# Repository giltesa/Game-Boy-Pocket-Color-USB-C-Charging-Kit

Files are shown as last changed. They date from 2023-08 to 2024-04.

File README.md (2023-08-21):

# Game Boy Pocket/Color: USB-C Charging Kit (GB2)

The **Game Boy Pocket/Color: USB-C Charging Kit**, or **GB2** as I like to call it, is a circuit that replaces the original power board of the **Game Boy Pocket** and **Game Boy Color**.

This circuit is a **multi-device** and versatile board with **multiple installation options**. This means that **this kit can be used for both Game Boy models**, and you can decide whether you want to **power your console with AA/AAA** batteries **or a rechargeable li-ion battery**. You can also choose between using the **original 2.5mm DC power connector** **or replacing it with a USB-C**. Additionally, you have **the option to install a light board that will indicate the status of the console and battery**, all from the original hole on the console, next to the screen.





### FEATURES

*   Exact **shape for Game Boy Pocket & Game Boy Color**.
*   **Power DC converter** of **5V** output. **(1)**
*   **External power** through **2.5mm DC jack** or **USB-C.** **(2)**
*   **Li-Ion battery charger** with overvoltage and undervoltage protection. **(2)**
*   **Safe charge and play**.
*   **Integrated LED indicators** on the main board, next to the battery connector for charging battery (red) and full battery (green). It can be disabled by the jumper SJ1.
*   **External LED indicators** board for playing (white), charging battery (red) and full battery (green). Optional installation.

**(1)** Provides stable power to your Game Boy, IPS screen, and flash card. However, it doesn't supply the -19v rail, which means the stock screen or GBP IPS screen, which adjusts brightness through the contrast wheel, will not be able to change the brightness level and will remain at its maximum level.

**(2)** The USB-C and li-ion battery require trimming of the shell. Please refer to the PDF installation manual for more information.

https://www.youtube.com/watch?v=UszhrSf1U5U

## Would you like it?

https://shop.giltesa.com/product/game-boy-pocket-color-usb-c-charging-kit/

## More

- [giltesa.com](https://giltesa.com "giltesa.com")
- [twitter.com](https://twitter.com/giltesa "twitter.com")

## License

This project is licensed under a **Creative Commons** license:
**[Attribution-NonCommercial-ShareAlike 4.0 International (CC BY-NC-SA 4.0) ](https://creativecommons.org/licenses/by-nc-sa/4.0/)**

Check the [LICENSE.md](LICENSE.md) for more information.

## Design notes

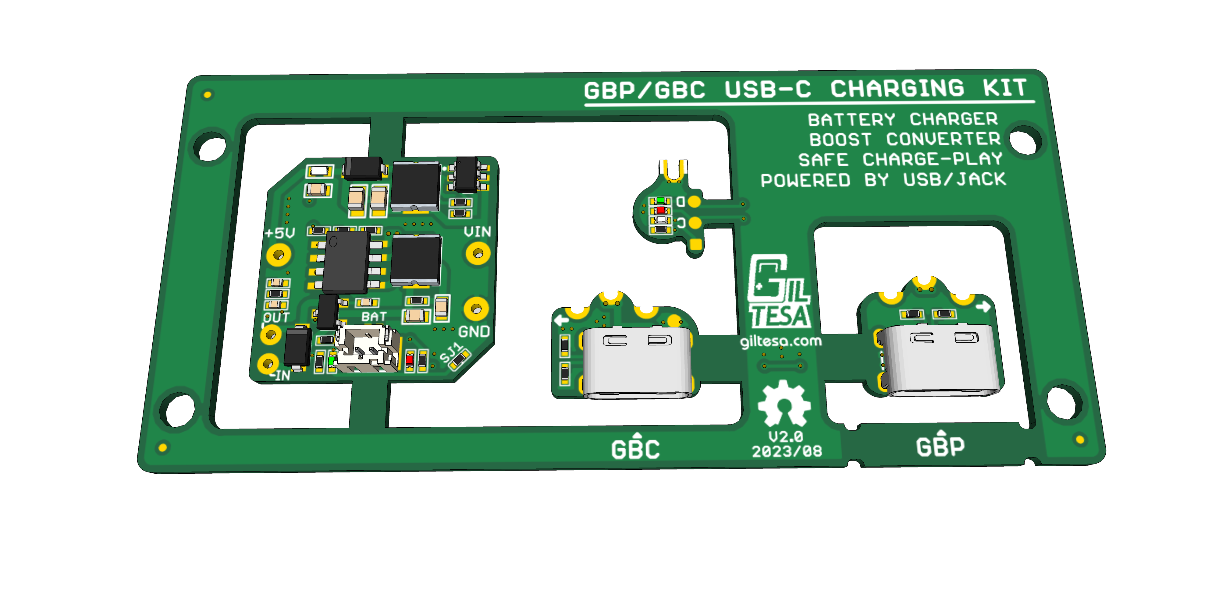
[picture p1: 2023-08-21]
2. Renders, 3D models/GB2 USB-C Charging Kit v2.0.png

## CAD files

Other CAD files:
2. Renders, 3D models/GB2 USB-C Charging Kit v2.0.skp

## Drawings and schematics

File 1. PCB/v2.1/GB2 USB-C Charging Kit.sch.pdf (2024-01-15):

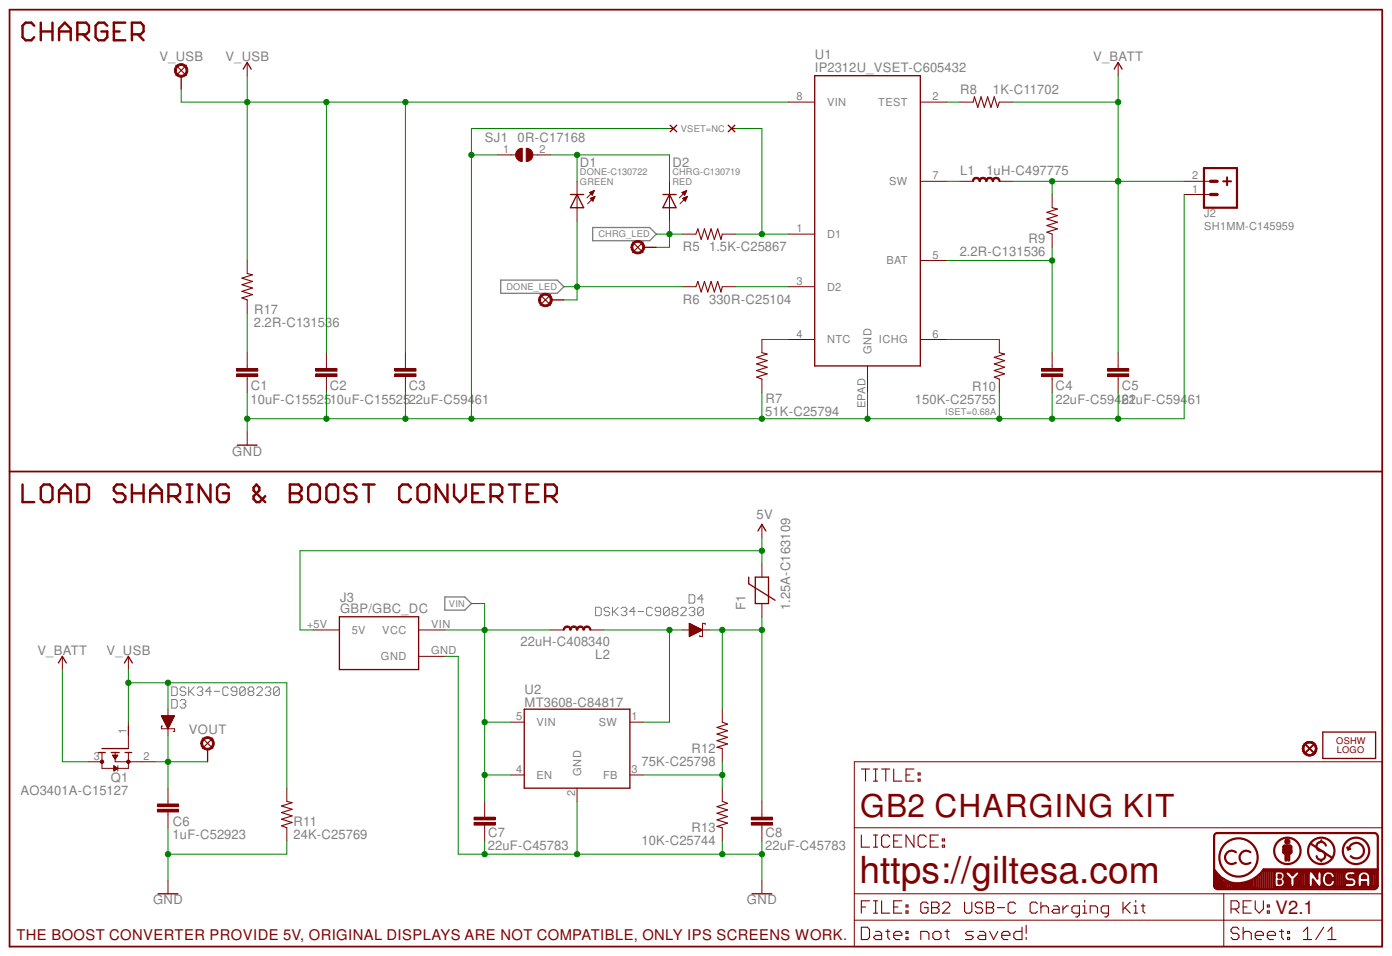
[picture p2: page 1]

THE BOOST CONVERTER PROVIDE 5V, ORIGINAL DISPLAYS ARE NOT COMPATIBLE, ONLY IPS SCREENS WORK.

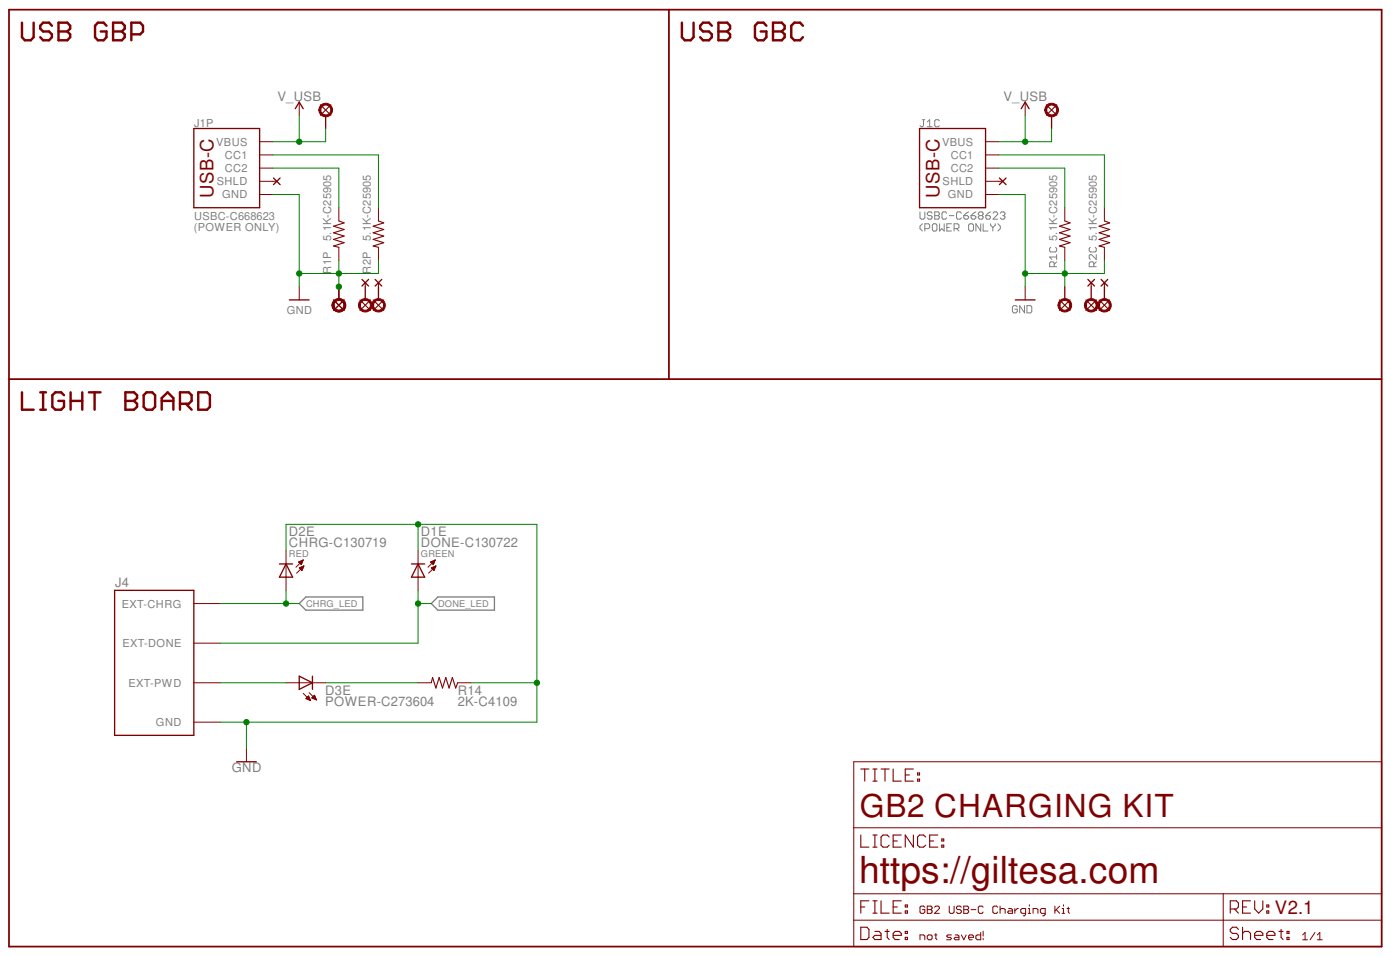
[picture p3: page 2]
RED; GREEN; (POWER ONLY); V_USB; 5.1K-C25905 USBC-C668623; GND; CHRG-C130719; DONE-C130722; POWER-C273604; VBUS CC1 CC2 SHLD; EXT-PWD; EXT-CHRG; EXT-DONE; CHRG_LED; DONE_LED; USB-C

GB2 CHARGING KIT
https://giltesa.com

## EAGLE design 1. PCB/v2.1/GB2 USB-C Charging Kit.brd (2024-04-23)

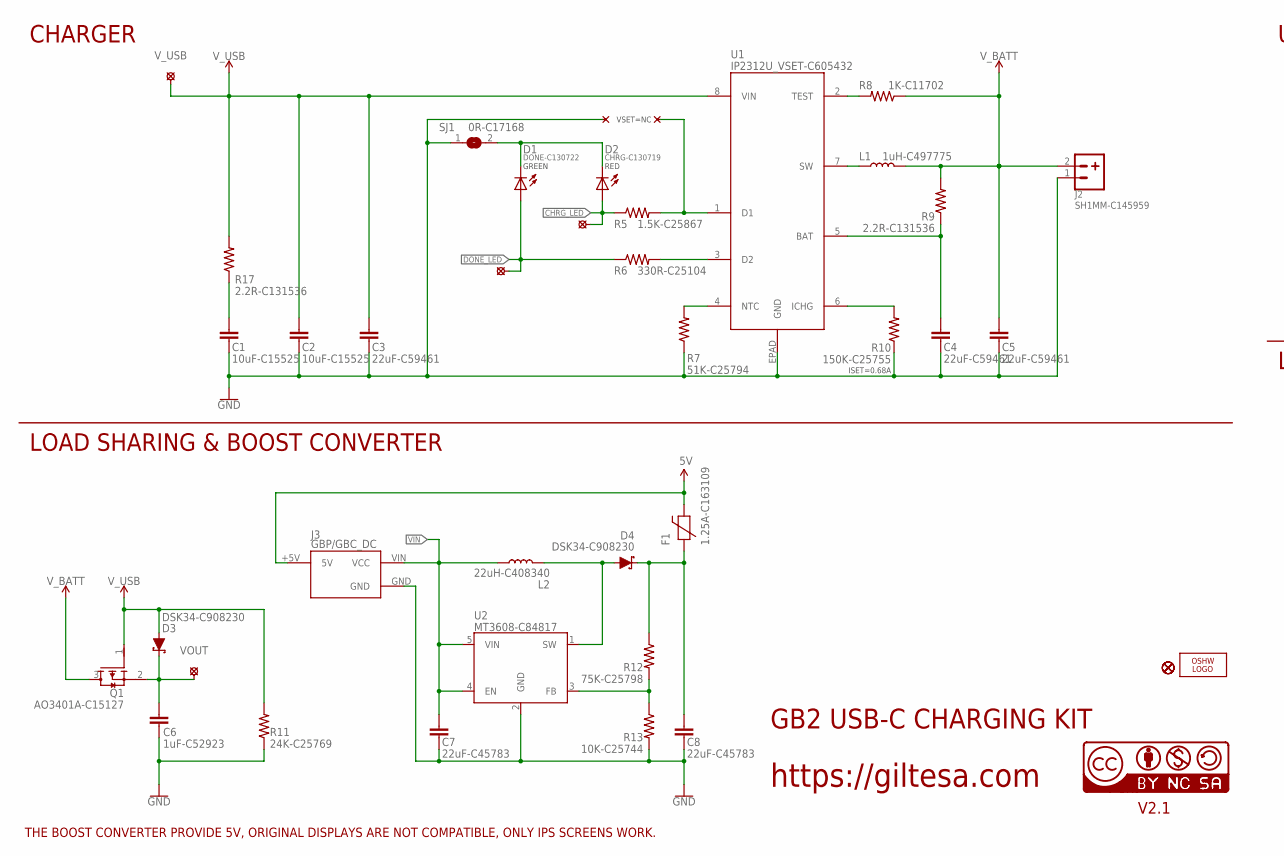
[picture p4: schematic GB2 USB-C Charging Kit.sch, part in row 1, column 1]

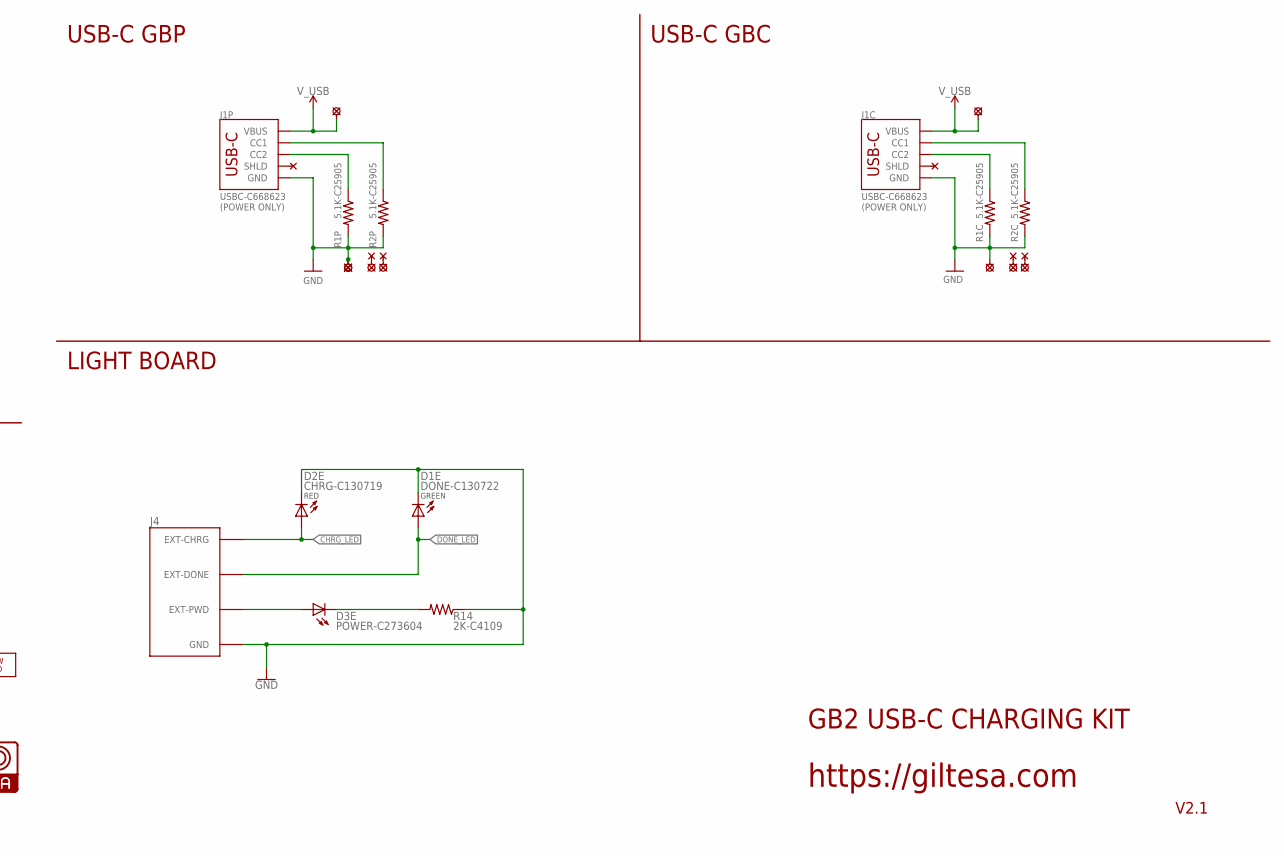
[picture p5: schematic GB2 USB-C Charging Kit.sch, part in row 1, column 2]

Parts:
C1, C2: 10uF-C15525; C0402_S
C3, C4, C5: 22uF-C59461; C0603_S
C6: 1uF-C52923; C0402_S
C7, C8: 22uF-C45783; C0805_S
D1, D1E: DONE-C130722; L0402
D2, D2E: CHRG-C130719; L0402
D3, D4: DSK34-C908230; SOD-123FL
D3E: POWER-C273604; L0402
F1: 1.25A-C163109; F0603_S
FD1, FD2, FD3: FIDUCIALUFIDUCIAL; FIDUCIAL-MICRO
J1C, J1P: USBC-C668623; USB-C_6P
J2: SH1MM-C145959; JST-2-1MM-SMD_TOP
J3: GBP/GBC_DC; GB2_DC-DC
J4: GB2_LED
L1: 1uH-C497775; PSPMAA0402
L2: 22uH-C408340; PSPMAA0402
LOGO1: OSHW_LOGO_FILLX0150-NT; OSHW_FILLX150_NOTEXT
Q1: AO3401A-C15127; SOT23-3_S
R1C, R1P, R2C, R2P: 5.1K-C25905; R0402
R5: 1.5K-C25867; R0402
R6: 330R-C25104; R0402
R7: 51K-C25794; R0402
R8: 1K-C11702; R0402
R9, R17: 2.2R-C131536; R0402
R10: 150K-C25755; R0402
R11: 24K-C25769; R0402
R12: 75K-C25798; R0402
R13: 10K-C25744; R0402
R14: 2K-C4109; R0402
SJ1: 0R-C17168; JUMPER-SMD_0402
U1: IP2312U_VSET-C605432; IP2312
U2: MT3608-C84817; SOT-23-6
U$2, U$11, U$15, U$19, U$25, U$33: PAD_1.1
U$13: CC-NC-BCNIX; CC-NC-B_NIX
U$20, U$21: SOLDER_PAD-1.7; SOLDER_PAD_1.7
U$23: VOUT; PAD_0.8
U$24: V_USB; PAD_0.8
U$26, U$27: SOLDER_PAD-2.0; SOLDER_PAD_2.0
U$32: SOLDER_PAD-2.5; SOLDER_PAD_2.5

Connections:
5V: F1.2, J3.+5V (5V)
CHRG_LED: D2.A, D2E.A, J4.EXT-CHRG, R5.1, U$21.P$1
DONE_LED: D1.A, D1E.A, J4.EXT-DONE, R6.1, U$20.P$1
GND: C1.1, C2.1, C3.1, C4.1, C5.1, C6.2, C7.1, C8.1, D1E.C, D2E.C, J1C.A12-GND (GND), J1C.B12-GND (GND), J1P.A12-GND (GND), J1P.B12-GND (GND), J2.1, J3.GND, J4.GND1 (GND), J4.GND2 (GND), J4.GND3 (GND), J4.GND4 (GND), J4.GND5 (GND), R1C.2, R1P.2, R2C.2, R2P.2, R7.1, R10.1, R11.1, R13.2, R14.1, SJ1.1, U1.EPAD (GND), U2.2 (GND), U$19.P$1, U$26.P$1, U$27.P$1
unnamed: J1C.B5 (CC2), R1C.1
unnamed: J1P.A5 (CC1), R2P.1
unnamed: J1P.B5 (CC2), R1P.1
unnamed: D4.A, L2.P$2 (2), U2.1 (SW)
unnamed: D1.C, D2.C, SJ1.2
unnamed: D3E.A, J4.EXT-PWD, J4.EXT-PWD' (EXT-PWD)
unnamed: D3E.C, R14.2
unnamed: R12.2, R13.1, U2.3 (FB)
unnamed: J1C.A5 (CC1), R2C.1
unnamed: C8.2, D4.C, F1.1, R12.1
unnamed: C4.2, R9.1, U1.5 (BAT)
unnamed: R8.2, U1.2 (TEST)
unnamed: C1.2, R17.1
unnamed: R5.2, U1.1 (D1)
unnamed: R7.2, U1.4 (NTC)
unnamed: R10.2, U1.6 (ICHG)
unnamed: R6.2, U1.3 (D2)
unnamed: L1.P$1 (1), U1.7 (SW)
VCC: C6.1, D3.C, Q1.2 (S), U$23.P$1
VIN: C7.2, J3.VIN (VCC), L2.P$1 (1), U2.4 (EN), U2.5 (VIN)
V_BATT: C5.2, J2.2, L1.P$2 (2), Q1.3 (D), R8.1, R9.2
V_USB: C2.2, C3.2, D3.A, J1C.A9-VBUS (VBUS), J1C.B9-VBUS (VBUS), J1P.A9-VBUS (VBUS), J1P.B9-VBUS (VBUS), Q1.1 (G), R11.2, R17.2, U1.8 (VIN), U$24.P$1, U$25.P$1, U$33.P$1

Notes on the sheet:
(POWER ONLY)
GB2 USB-C CHARGING KIT
https://giltesa.com
V2.1
THE BOOST CONVERTER PROVIDE 5V, ORIGINAL DISPLAYS ARE NOT COMPATIBLE, ONLY IPS SCREENS WORK.
USB-C GBC
CHARGER
LOAD SHARING & BOOST CONVERTER
ISET=0.68A
GREEN
RED
VSET=NC
USB-C GBP
LIGHT BOARD

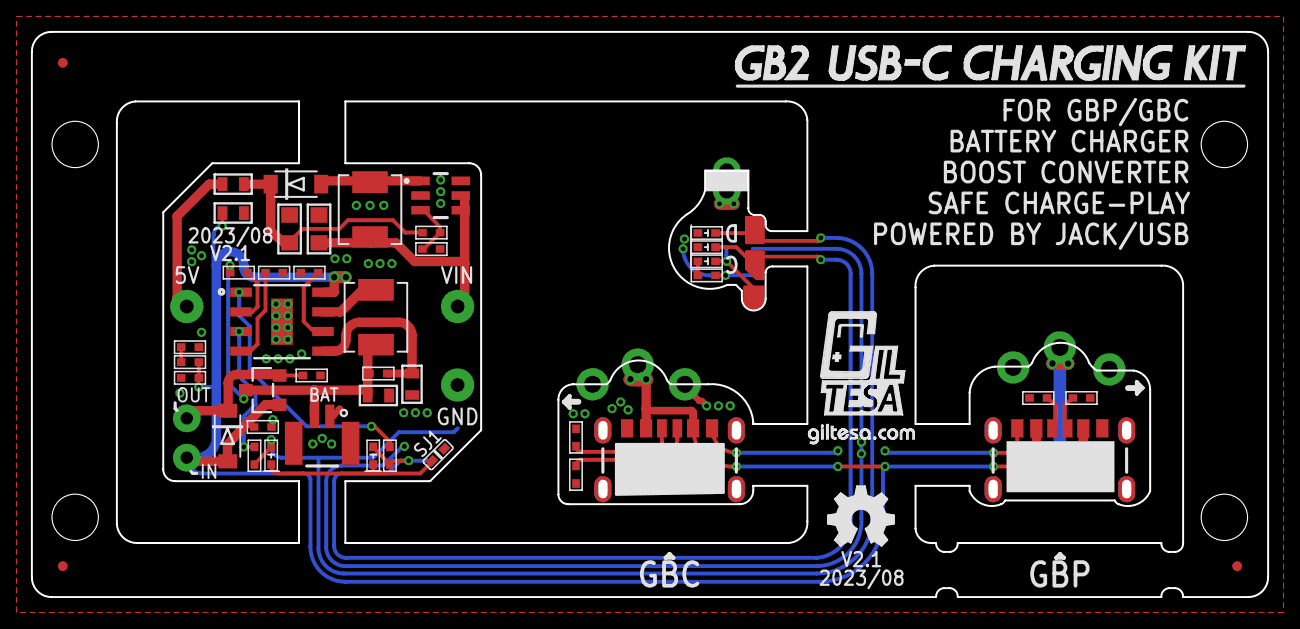
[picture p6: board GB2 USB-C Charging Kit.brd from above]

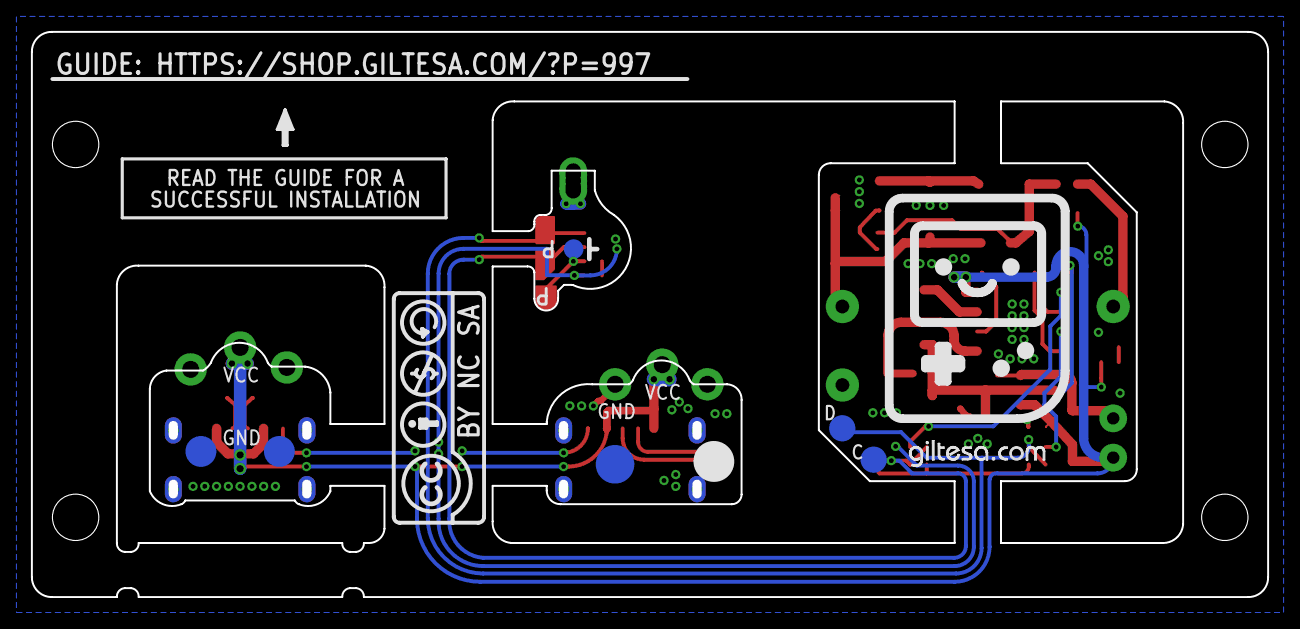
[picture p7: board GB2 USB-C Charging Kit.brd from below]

Board: 2 copper layers, 80.0 x 36.6 mm, 66 parts (8 on the bottom side), 26 nets.

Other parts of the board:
U$1: GILTESA_LOGO_MASK_7MM
U$4: GB2_FRAME
U$7: CC-BY-NC-SA15MM; CC-BY-NC-SA_15MM
U$22: GAME_BOY_2
U$28: GILTESA.COM_MASK_7MM
U$29: GILTESA.COM_MASK_9MM

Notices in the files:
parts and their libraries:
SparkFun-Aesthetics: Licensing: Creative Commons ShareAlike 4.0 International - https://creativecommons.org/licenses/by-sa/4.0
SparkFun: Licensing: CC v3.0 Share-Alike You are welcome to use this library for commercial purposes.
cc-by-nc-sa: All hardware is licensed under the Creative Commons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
